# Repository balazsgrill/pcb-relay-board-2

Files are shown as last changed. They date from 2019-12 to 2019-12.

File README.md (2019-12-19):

# pcb-relay-board-2
Printed Circuit Board for 5V Relays x8

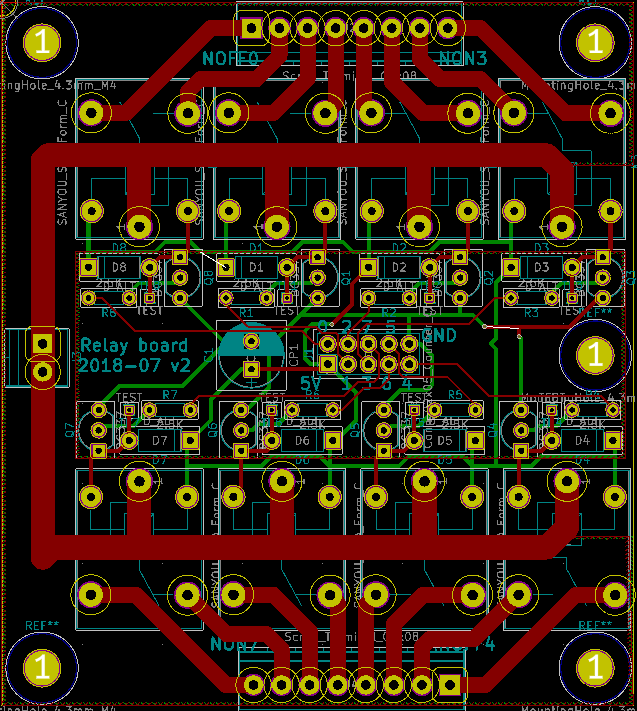
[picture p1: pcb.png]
PCB


## Bill of Materials

* Compatible relays: 5V coil / 230V-10A
  * Songle SRD-5VDC-SL-C
  * Zetter AZ943-1CH-5DE 
  * Hongfa HF3FA/005-ZT
  * Omron G5LE-1
  * Panasonic JS1-5V-F
* Transistors: BC337 or compatible (CBE layout)
* Diodes: 1N4148 or similar
* Resistors: 5K
* Capacitor: 100uF

## J1 connector pinout
| Function | Pin | Pin | Function |
| --- | --- | --- | --- |
| 5V | 1 | 2  | Relay 0  |
| Relay 1 | 3 | 4  | Relay 2  |
| Relay 3 | 5 | 6  | Relay 7  |
| Relay 4 | 7 | 8  | Relay 5  |
| Relay 5 | 9 | 10 | GND  |

## Errata

* On the silscreen, Normally on and Normally off indications (NONx and NOFFx respectively are reversed)

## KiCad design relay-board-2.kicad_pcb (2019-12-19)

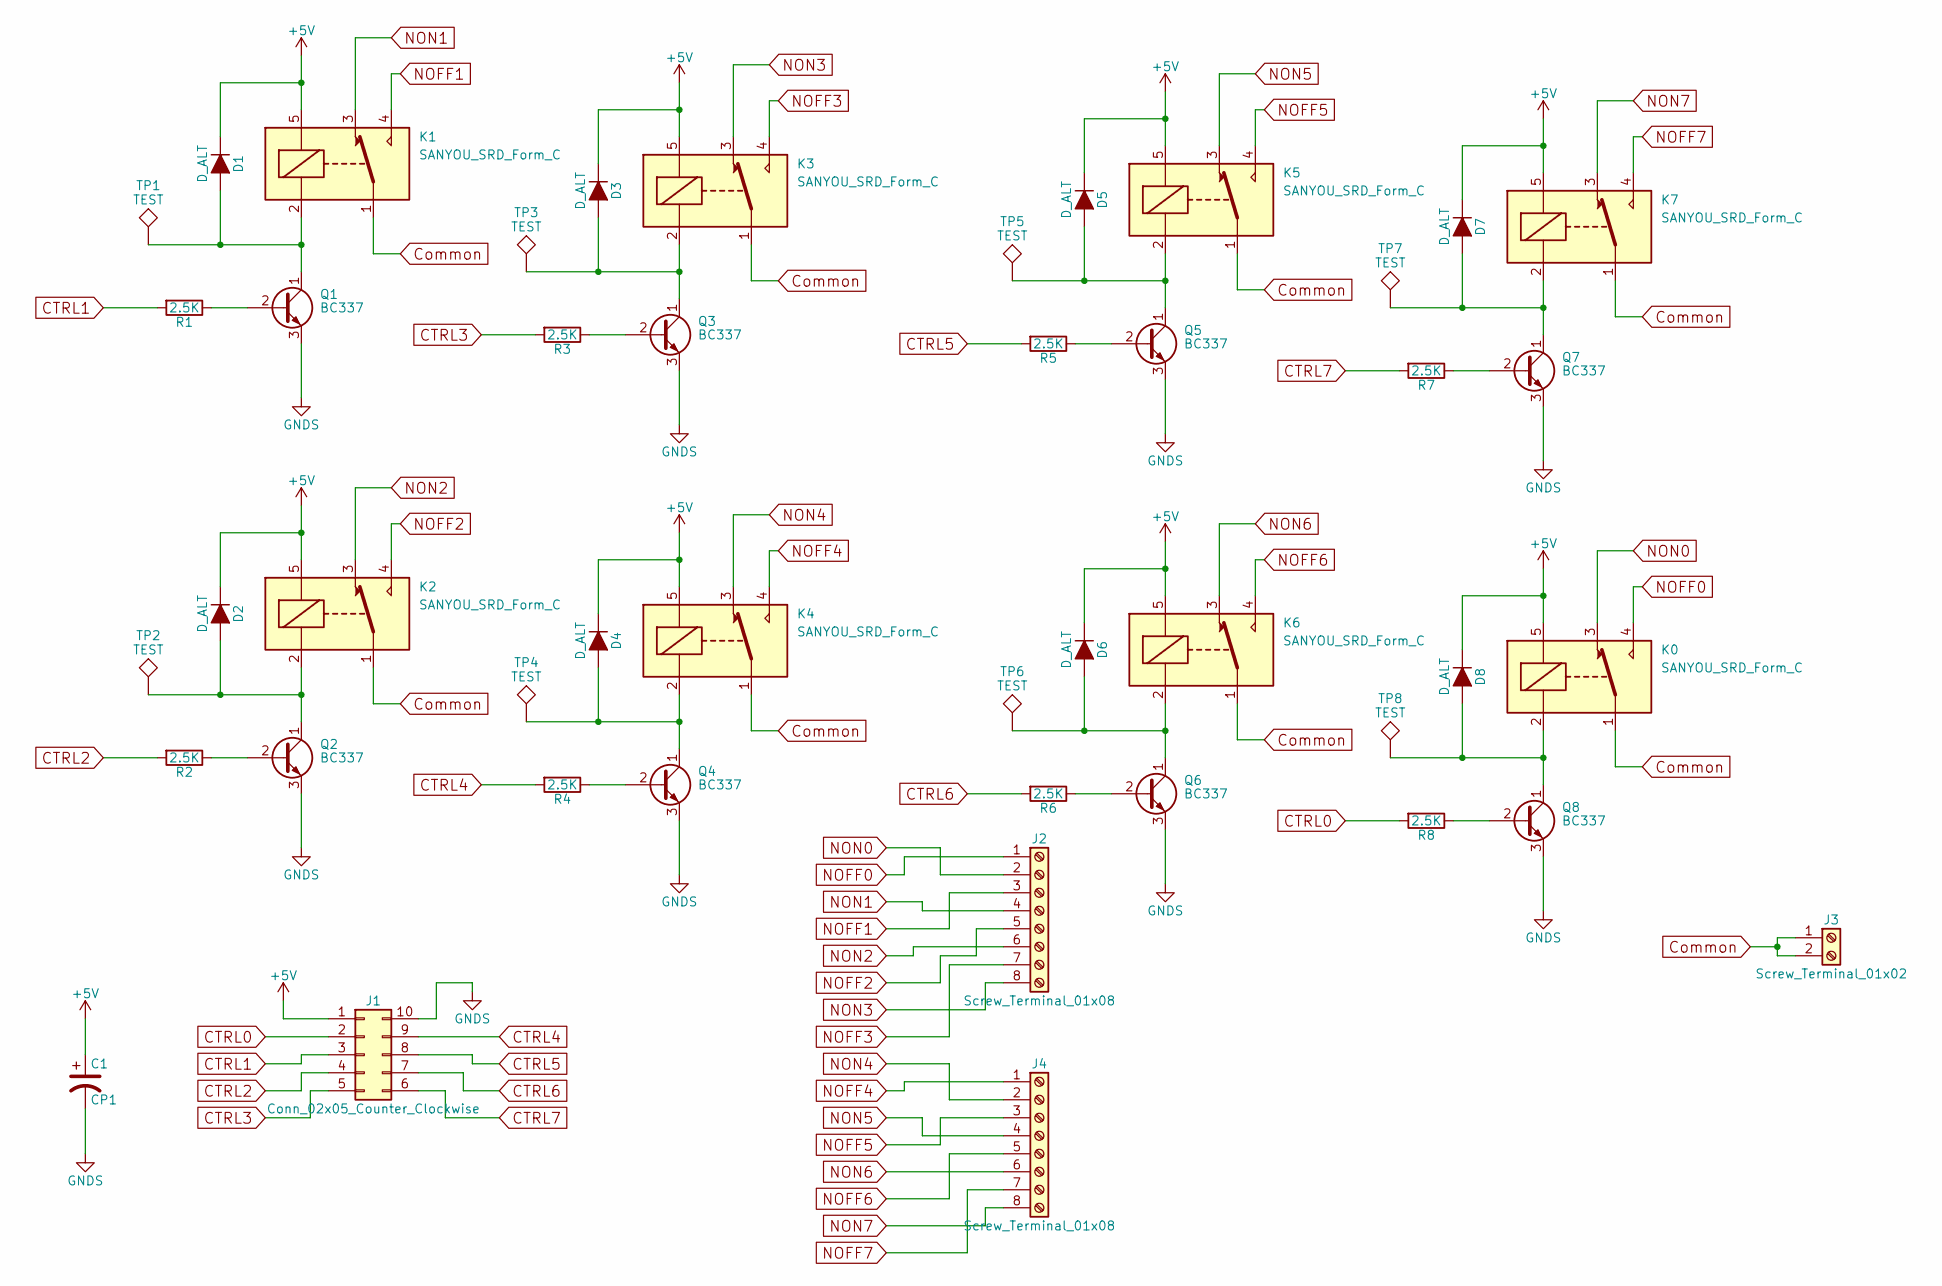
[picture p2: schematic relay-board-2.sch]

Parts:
C1: CP1; CP_Radial_D8.0mm_P3.50mm
D1, D2, D3, D4, D5, D6, D7, D8: D_ALT; D_A-405_P7.62mm_Horizontal
J1: Conn_02x05_Counter_Clockwise; Pin_Header_Straight_2x05_Pitch2.54mm
J2, J4: Screw_Terminal_01x08; TerminalBlock_Phoenix_PT-3.5mm_8pol
J3: Screw_Terminal_01x02; TerminalBlock_Phoenix_PT-3.5mm_2pol
K0, K1, K2, K3, K4, K5, K6, K7: SANYOU_SRD_Form_C; Relay_SPDT_SANYOU_SRD_Series_Form_C
Q1, Q2, Q3, Q4, Q5, Q6, Q7, Q8: BC337; TO-92_Inline_Wide
R1, R2, R3, R4, R5, R6, R7, R8: 2.5K; R_Axial_DIN0204_L3.6mm_D1.6mm_P5.08mm_Horizontal
TP1, TP2, TP3, TP4, TP5, TP6, TP7, TP8: TEST; Pin_Header_Straight_1x01_Pitch1.00mm

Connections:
+5V: C1.1, D1.1 (K), D2.1 (K), D3.1 (K), D4.1 (K), D5.1 (K), D6.1 (K), D7.1 (K), D8.1 (K), J1.1, K0.5, K1.5, K2.5, K3.5, K4.5, K5.5, K6.5, K7.5
CTRL0: J1.2, R8.2
CTRL1: J1.3, R1.2
CTRL2: J1.4, R2.2
CTRL3: J1.5, R3.2
CTRL4: J1.9, R4.2
CTRL5: J1.8, R5.2
CTRL6: J1.7, R6.2
CTRL7: J1.6, R7.2
Common: J3.1, J3.2, K0.1, K1.1, K2.1, K3.1, K4.1, K5.1, K6.1, K7.1
GNDS: C1.2, J1.10, Q1.3 (E), Q2.3 (E), Q3.3 (E), Q4.3 (E), Q5.3 (E), Q6.3 (E), Q7.3 (E), Q8.3 (E)
NOFF0: J2.1, K0.4
NOFF1: J2.3, K1.4
NOFF2: J2.5, K2.4
NOFF3: J2.7, K3.4
NOFF4: J4.1, K4.4
NOFF5: J4.3, K5.4
NOFF6: J4.5, K6.4
NOFF7: J4.7, K7.4
NON0: J2.2, K0.3
NON1: J2.4, K1.3
NON2: J2.6, K2.3
NON3: J2.8, K3.3
NON4: J4.2, K4.3
NON5: J4.4, K5.3
NON6: J4.6, K6.3
NON7: J4.8, K7.3
unnamed: D1.2 (A), K1.2, Q1.1 (C), TP1.1
unnamed: D2.2 (A), K2.2, Q2.1 (C), TP2.1
unnamed: D3.2 (A), K3.2, Q3.1 (C), TP3.1
unnamed: D4.2 (A), K4.2, Q4.1 (C), TP4.1
unnamed: D5.2 (A), K5.2, Q5.1 (C), TP5.1
unnamed: D6.2 (A), K6.2, Q6.1 (C), TP6.1
unnamed: D7.2 (A), K7.2, Q7.1 (C), TP7.1
unnamed: D8.2 (A), K0.2, Q8.1 (C), TP8.1
unnamed: Q1.2 (B), R1.1
unnamed: Q2.2 (B), R2.1
unnamed: Q3.2 (B), R3.1
unnamed: Q4.2 (B), R4.1
unnamed: Q5.2 (B), R5.1
unnamed: Q6.2 (B), R6.1
unnamed: Q7.2 (B), R7.1
unnamed: Q8.2 (B), R8.1

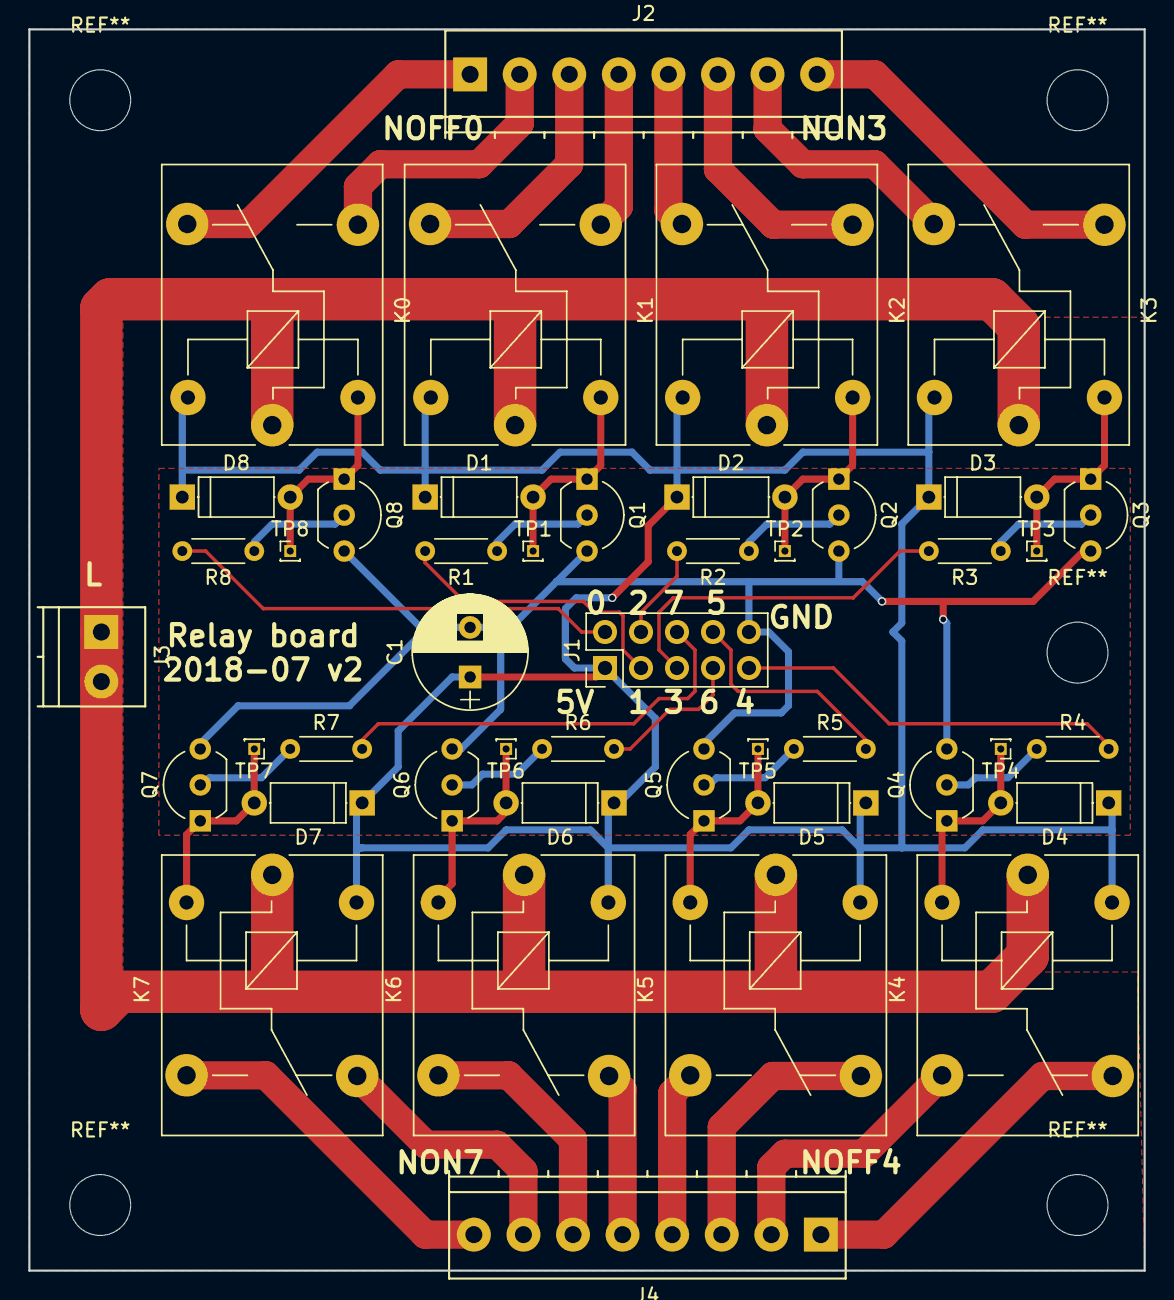
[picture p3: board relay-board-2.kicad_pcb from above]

Board: 2 copper layers, 78.7 x 87.6 mm, 45 parts (0 on the bottom side), 43 nets.
